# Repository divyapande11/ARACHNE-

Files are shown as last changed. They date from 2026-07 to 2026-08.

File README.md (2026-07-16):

# ARACHNE-
ARACHNE is a 6-legged, 12-servo walking robot built around two focused technical challenges, deliberately scoped down from an earlier multi-part design to ensure depth over breadth: coordinated multi-servo gait generation and real-time obstacle detection with behavioral response. The project uses an ESP32-S3 as the control core, a custom PCB, and a modified mechanical frame of bot having six legs and a main body.

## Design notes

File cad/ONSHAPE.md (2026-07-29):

\# Onshape CAD Model

This project's CAD model is hosted on Onshape.

\## CAD Link

https://cad.onshape.com/documents/fa7984808dd8120eb4ebba79/w/f01733864455828bc5df7434/e/2305df5b508feb92c4281371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\&uiState=6a6a4392be776e17aefb1e8f

\## Notes

\- Platform: Onshape

\- This document contains the latest CAD design for the ARACHNE project.

\- Please ensure you have permission to access the document.

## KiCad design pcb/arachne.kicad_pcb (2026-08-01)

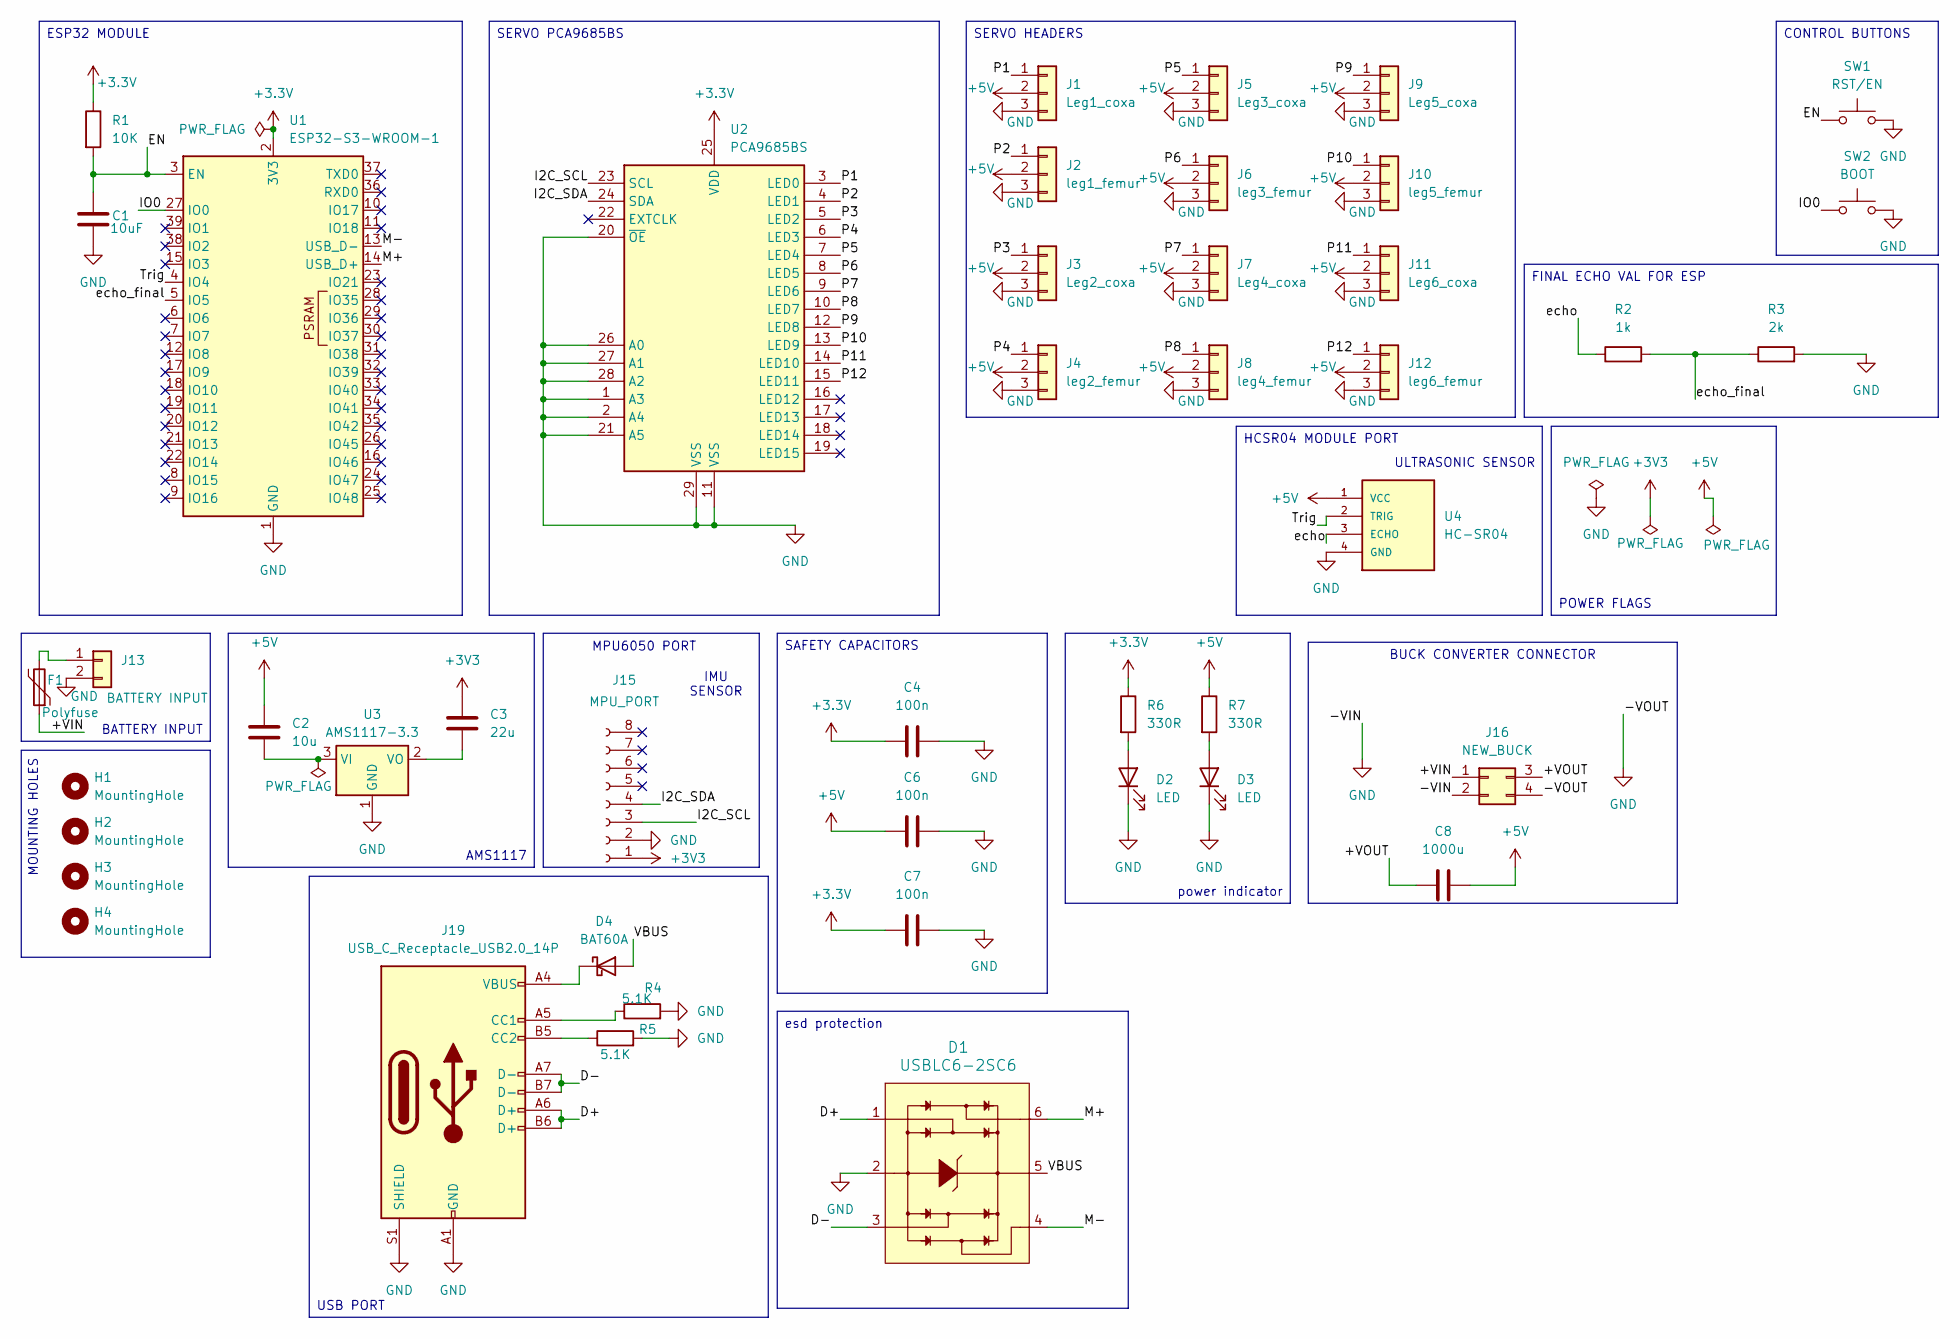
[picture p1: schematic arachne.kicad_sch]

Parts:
C1: 10uF; C_0805_2012Metric
C2: 10u; C_0805_2012Metric
C3: 22u; C_1206_3216Metric
C4, C6, C7: 100n; C_0805_2012Metric
C8: 1000u; C_Radial_D10.0mm_H12.5mm_P5.00mm
D1: USBLC6-2SC6; SOT-23-6; MPN USBLC6-2SC6; Digi-Key_PN 497-5235-1-ND
D2, D3: LED; LED_0603_1608Metric
D4: BAT60A; D_SOD-323
F1: Polyfuse; Fuse_1206_3216Metric
H1, H2, H3, H4: MountingHole; MountingHole_3.2mm_M3
J1: Leg1_coxa; PinHeader_1x03_P2.54mm_Vertical
J2: leg1_femur; PinHeader_1x03_P2.54mm_Vertical
J3: Leg2_coxa; PinHeader_1x03_P2.54mm_Vertical
J4: leg2_femur; PinHeader_1x03_P2.54mm_Vertical
J5: Leg3_coxa; PinHeader_1x03_P2.54mm_Vertical
J6: leg3_femur; PinHeader_1x03_P2.54mm_Vertical
J7: Leg4_coxa; PinHeader_1x03_P2.54mm_Vertical
J8: leg4_femur; PinHeader_1x03_P2.54mm_Vertical
J9: Leg5_coxa; PinHeader_1x03_P2.54mm_Vertical
J10: leg5_femur; PinHeader_1x03_P2.54mm_Vertical
J11: Leg6_coxa; PinHeader_1x03_P2.54mm_Vertical
J12: leg6_femur; PinHeader_1x03_P2.54mm_Vertical
J13: BATTERY INPUT; TerminalBlock_Phoenix_MKDS-1,5-2-5.08_1x02_P5.08mm_Horizont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
J15: MPU_PORT; PinHeader_1x08_P2.54mm_Vertical
J16: NEW_BUCK; PinHeader_2x02_P2.54mm_Vertical
J19: USB_C_Receptacle_USB2.0_14P; USB_C_Receptacle_HRO_TYPE-C-31-M-12
R1: 10K; R_0805_2012Metric
R2: 1k; R_0805_2012Metric
R3: 2k; R_0805_2012Metric
R4, R5: 5.1K; R_0805_2012Metric
R6, R7: 330R; R_0805_2012Metric
SW1: RST/EN; SW_PUSH_6mm
SW2: BOOT; SW_PUSH_6mm
U1: ESP32-S3-WROOM-1
U2: PCA9685BS; QFN-28-1EP_6x6mm_P0.65mm_EP4.25x4.25mm
U3: AMS1117-3.3; SOT-223-3_TabPin2
U4: HC-SR04; XCVR_HC-SR04

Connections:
+3.3V: C4.1, C7.1, R1.1, R6.1, U1.2 (3V3), U2.25 (VDD)
+3V3: C3.1, J15.1
+5V: C2.1, C6.1, C8.1, J1.2, J2.2, J3.2, J4.2, J5.2, J6.2, J7.2, J8.2, J9.2, J10.2, J11.2, J12.2, R7.1, U4.1 (VCC)
/+VIN: F1.1, J16.1
/+VOUT: C8.2, J16.3
/D+: D1.1, J19.A6 (D+), J19.B6 (D+)
/D-: D1.3, J19.A7 (D-), J19.B7 (D-)
/EN: C1.1, R1.2, SW1.1, U1.3 (EN)
/I2C_SCL: J15.3, U2.23 (SCL)
/I2C_SDA: J15.4, U2.24 (SDA)
/IO0: SW2.1, U1.27 (IO0)
/M+: D1.6, U1.14 (USB_D+)
/M-: D1.4, U1.13 (USB_D-)
/P1: J1.1, U2.3 (LED0)
/P2: J2.1, U2.4 (LED1)
/P3: J3.1, U2.5 (LED2)
/P4: J4.1, U2.6 (LED3)
/P5: J5.1, U2.7 (LED4)
/P6: J6.1, U2.8 (LED5)
/P7: J7.1, U2.9 (LED6)
/P8: J8.1, U2.10 (LED7)
/P9: J9.1, U2.12 (LED8)
/P10: J10.1, U2.13 (LED9)
/P11: J11.1, U2.14 (LED10)
/P12: J12.1, U2.15 (LED11)
/Trig: U1.4 (IO4), U4.2 (TRIG)
/VBUS: D1.5, D4.2 (A)
/echo: R2.1, U4.3 (ECHO)
/echo_final: R2.2, R3.1, U1.5 (IO5)
GND: C1.2, C4.2, C6.2, C7.2, D1.2, D2.1 (K), D3.1 (K), J1.3, J2.3, J3.3, J4.3, J5.3, J6.3, J7.3, J8.3, J9.3, J10.3, J11.3, J12.3, J13.2, J15.2, J16.2, J16.4, J19.A1 (GND), J19.A12 (GND), J19.B1 (GND), J19.B12 (GND), J19.S1 (SHIELD), R3.2, R4.2, R5.2, SW1.2, SW2.2, U1.1 (GND), U1.40 (GND), U1.41 (GND), U2.1 (A3), U2.2 (A4), U2.11 (VSS), U2.20 (~OE), U2.21 (A5), U2.26 (A0), U2.27 (A1), U2.28 (A2), U2.29 (VSS), U3.1 (GND), U4.4 (GND)
unnamed: D2.2 (A), R6.2
unnamed: D3.2 (A), R7.2
unnamed: D4.1 (K), J19.A4 (VBUS), J19.A9 (VBUS), J19.B4 (VBUS), J19.B9 (VBUS)
unnamed: F1.2, J13.1
unnamed: J19.A5 (CC1), R4.1
unnamed: J19.B5 (CC2), R5.1
unnamed: C2.2, U3.3 (VI)
unnamed: C3.2, U3.2 (VO)

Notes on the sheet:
MPU6050 PORT
IMU SENSOR
ULTRASONIC SENSOR
BATTERY INPUT
USB PORT
MOUNTING HOLES
CONTROL BUTTONS
POWER FLAGS
SERVO PCA9685BS
SERVO HEADERS
BUCK CONVERTER CONNECTOR
HCSR04 MODULE PORT
power indicator
AMS1117
ESP32 MODULE
SAFETY CAPACITORS
FINAL ECHO VAL FOR ESP
esd protection

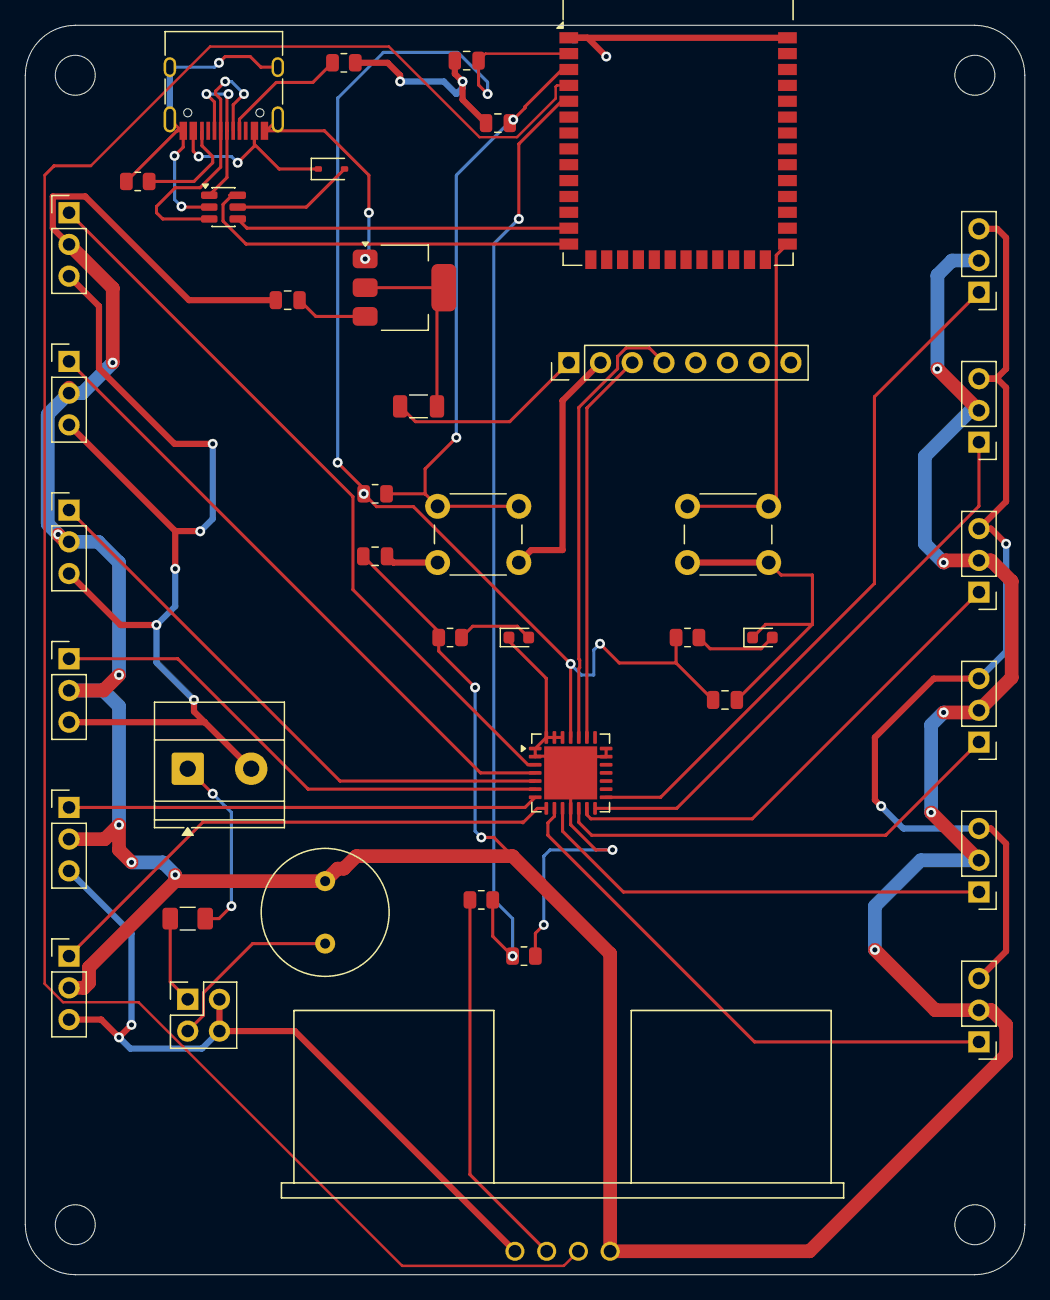
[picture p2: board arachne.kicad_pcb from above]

Board: 2 copper layers, 80.0 x 100.0 mm, 45 parts (0 on the bottom side), 38 nets.

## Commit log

2026-07-14 ros simulate also a basic cad
2026-07-16 Add KiCad schematic and PCB files
    [arachne.kicad_pcb, arachne.kicad_sch]
2026-07-29 Update PCB routing and KiCad project
    [arachne.kicad_pcb, arachne.kicad_sch]
2026-07-29 removing step file initially
    [Part Studio 1.step]
2026-08-01 oraganized repo
    [arachne.kicad_pcb, arachne.kicad_sch]
2026-08-01 final pcb routed
    [arachne.kicad_pcb]
